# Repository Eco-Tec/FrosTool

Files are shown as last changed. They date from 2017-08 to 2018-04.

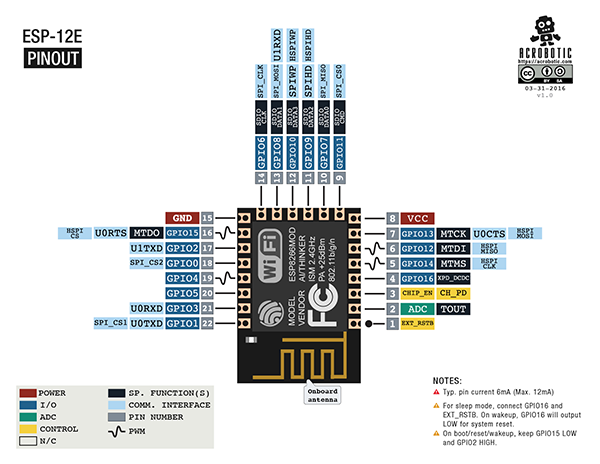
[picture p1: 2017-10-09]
Docs/ESP8266/esp8266_esp12e_pinout.png

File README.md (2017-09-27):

## FrosTool
Herramienta de monitoreo de variables climaticas para la generación de alertas tempranas para mitiga los efectos de las heladas en los cultivos del departamento de Boyaca- Col

# Arbol de directorios
- 3D-Model: Diseños de lo relacionado con las sondas, cajas, soportes, etc.
- Articulo: Contiene un Articulo cort ode investigación enformato IEEE.
- Docs: Contiene la documentación o linkeos hacia la misma (Texto, links, Imagenes)
- Hardware: Referente al hardware desarrollado (Esquemas, PCBs)
- Images: Aqui colocar imagenes solamente referente a el desarrollo del proyecto.
- Software: Principalmente el codigo desarrollado para el proeycto.

# Attributions
Basada en la idea de 
Fabián Andrés Salamanca Figueroa, Willmar Arbey Suarez Rodriguez, Christian Camilo Cárdenas Gamboa
https://github.com/fandres/Monitor-heladas

Este Proyecto
- @fandres
- @maurinc2010

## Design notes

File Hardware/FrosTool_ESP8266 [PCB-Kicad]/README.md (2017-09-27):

# Model 3D on FreeCad
============

License 
======

[Creative Commons Attribution-ShareAlike 4.0 International License](http://creativecommons.org/licenses/by-sa/4.0/)

Attributions
============
See commit details to find the authors of each Part.
- @fandres
- @maurinc2010

Schematic symbols and PCB footprints for ESP8266 modules 
- Copyright 2015,2016 J.Dunmire, kicad-ESP8266 is licensed under the Creative Commons Attribution-ShareAlike
4.0 International License. To view a copy of this license visit
http://creativecommons.org/licenses/by-sa/4.0/.

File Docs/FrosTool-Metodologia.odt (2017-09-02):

Compotentes y dispositivos

Actividad | Tarea | Producto
Sensores
Broker
Materiales sonda | Acondicimiento de la estructura fisica.

Protocolos de telecomunicación

Actividad | Tarea | Producto

Software & Firmware

Actividad | Tarea | Producto
Definir sofware
Definir firmware

App Celular

Actividad | Tarea | Producto
MqttDash

Autonomia Energetica

Actividad | Tarea | Producto
Calcular potencia requerida Modulo
Calcular potencia requerida Broker
Definir autonomia
Calculo Panel
Test baterias
Diseño PCB (Fuente)
Test Panel y fuente

GUI-Touch

Actividad | Tarea | Producto
Definir pantallas
| Perifericos de entrada

Base sensores (Estructura)

Actividad | Tarea | Producto
Diseño de sonda (Fisico)

Algoritmo predicción

Actividad | Tarea | Producto

Nube

Actividad | Tarea | Producto
Dpediente

Automatización

Actividad | Tarea | Producto
Definir tecnologia a usar.

Otras

Actividad | Tarea | Producto
Estado del arte: | Nuemro de sensores por metro cuadrado
Compra anemometro
Protección contra descargas electricas.

https://github.com/Eco-Tec/FrosTool/projects/1

© Esta obra está licenciada bajo la Licencia Creative Commons Atribución 4.0 Internacional. Para ver una copia de esta licencia, visita http://creativecommons.org/licenses/by/4.0/.

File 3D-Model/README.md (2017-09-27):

# Model 3D on FreeCad

# License 

[Creative Commons Attribution-ShareAlike 4.0 International License](http://creativecommons.org/licenses/by-sa/4.0/)

# Attributions

See commit details to find the authors of each Part.
- @fandres

Las piezas o partes usadas y modeladas en 3D de la carpeta parts son diseñadas por terceros

├── Broker
│   └── orange-pi-zero-v1-1-1-carly_mx.2
└── Node
    ├── 18650-by_Nursultan_Uzbekov
    ├── DHT22-by_Gistroy
    ├── esp8266-by_Andrey_Chirva
    ├── esp8266-esp01-by_ceodor_schumacher
    └── nodemcu-lua-wifi-by_Francisco_Castells

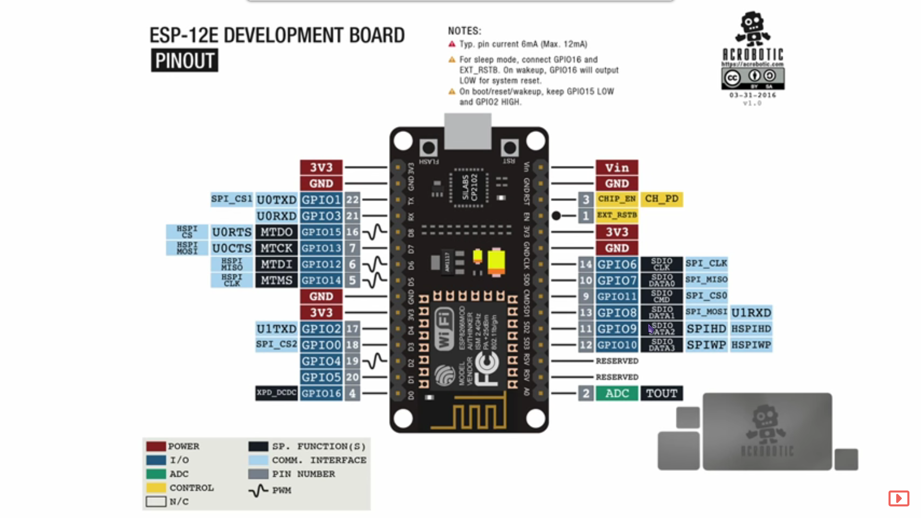
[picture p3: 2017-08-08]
Docs/ESP8266/ESP-12E-Placa de desarrollo.png

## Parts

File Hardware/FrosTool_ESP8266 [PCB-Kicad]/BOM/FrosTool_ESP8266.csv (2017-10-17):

Title | PCB-Kicad FrosTool
Revision | 1
Date
Generated | lun 16 oct 2017 20:20:48 -05
Company | Eco-Tec
Comment 1 | @maurinc2010
Comment 2 | @fAndReS
Comment 3
Comment 4
Total Parts | 38
Total Unique Parts | 28
Ref | Qty | Value | Footprint
C1 | 1 | 100nF | Capacitors_SMD:C_0805
C2 C3 | 2 | 10uF | Capacitors_SMD:c_elec_4x5.3
C4 | 1 | 10uF | Capacitors_SMD:C_0805
D1 | 1 | LED_DEBUG | LEDs:LED-3MM
D2 | 1 | CHRG_R | LEDs:LED-3MM
D3 | 1 | STDBY_G | LEDs:LED-3MM
J5 | 1 | DATA_S1 | Pin_Headers:Pin_Header_Straight_1x01
J8 | 1 | GPIO14(D/A) | Pin_Headers:Pin_Header_Straight_1x01
J1 | 1 | IN_PANEL | Pin_Headers:Pin_Header_Straight_1x02_Pitch2.00mm
J2 | 1 | BATERIA | Pin_Headers:Pin_Header_Straight_1x02_Pitch2.00mm
J14 J15 J13 | 3 | GND | Pin_Headers:Pin_Header_Straight_1x01
J10 J11 J12 | 3 | V3.3 | Pin_Headers:Pin_Header_Straight_1x01
J3 | 1 | TX_RX | Pin_Headers:Pin_Header_Straight_1x02_Pitch2.00mm
J6 | 1 | GPIO12(D/A) | Pin_Headers:Pin_Header_Straight_1x01
J7 J4 J9 | 3 | GPIO13(D) | Pin_Headers:Pin_Header_Straight_1x01
J16 | 1 | BAT+
Q1 | 1 | 2N3904 | TO_SOT_Packages_SMD:SOT-23
R5 | 1 | 470 | Resistors_SMD:R_1206
R4 R7 R8 | 3 | 1k | Resistors_SMD:R_1206
R3 R1 | 2 | 4.7k | Resistors_SMD:R_1206
R2 | 1 | 0 | Resistors_SMD:R_1206
R6 | 1 | 0.4 | Resistors_SMD:R_1206
R9 | 1 | 1.2k | Resistors_SMD:R_1206
SW2 | 1 | Flash | Buttons_Switches_SMD:SW_SPST_B3U-1000P
SW1 | 1 | Reset | Buttons_Switches_SMD:SW_SPST_B3U-1000P
U2 | 1 | ESP-12E | ESP8266:ESP-12E_SMD
U1 | 1 | HT7333-1 | TO_SOT_Packages_SMD:SOT89-3_Housing
U3 | 1 | TP4056 | Housings_SOIC:SOIC-8_3.9x4.9mm_Pitch1.27mm
BOM made with KICAD_BOM_WIZARD (https://github.com/HashDefineElectronics/KiCad_BOM_Wizard.git)
Generated lun 16 oct 2017 20:20:48 -05

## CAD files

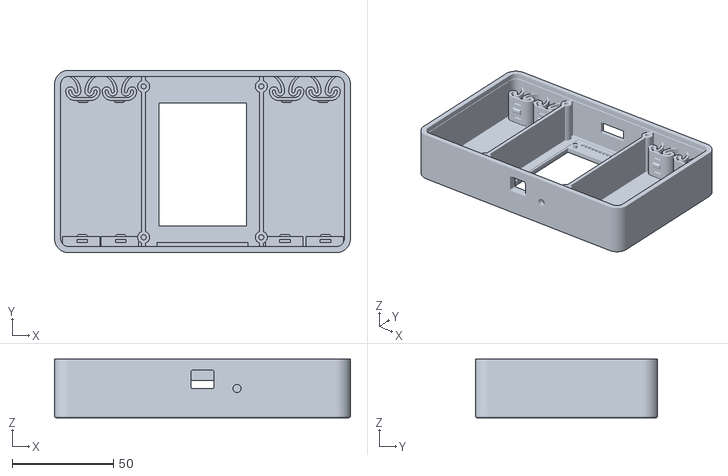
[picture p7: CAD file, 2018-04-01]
3D-Model/Broker/Case_Broker-A.stl
146.0 x 90.0 x 29.0

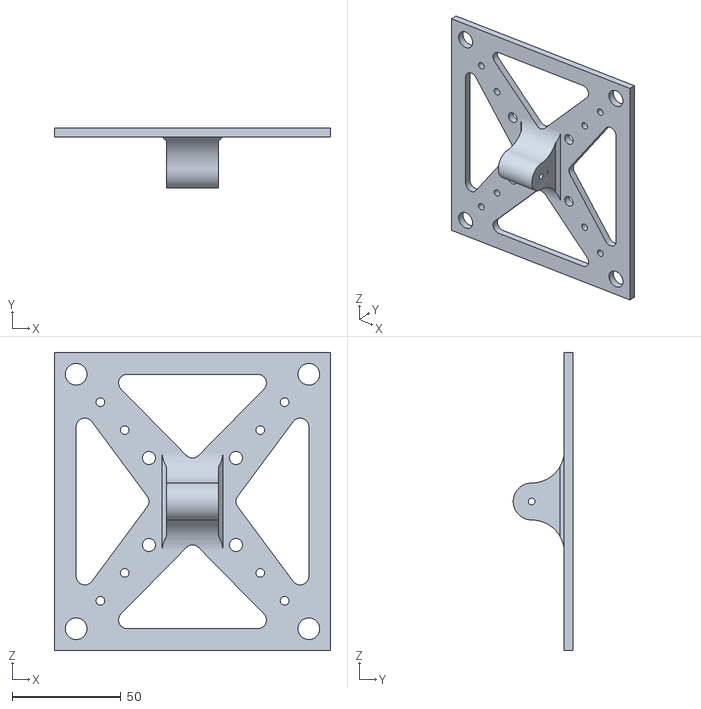
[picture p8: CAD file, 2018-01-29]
3D-Model/Node/SUPP_3.stl
127.0 x 27.4 x 137.0

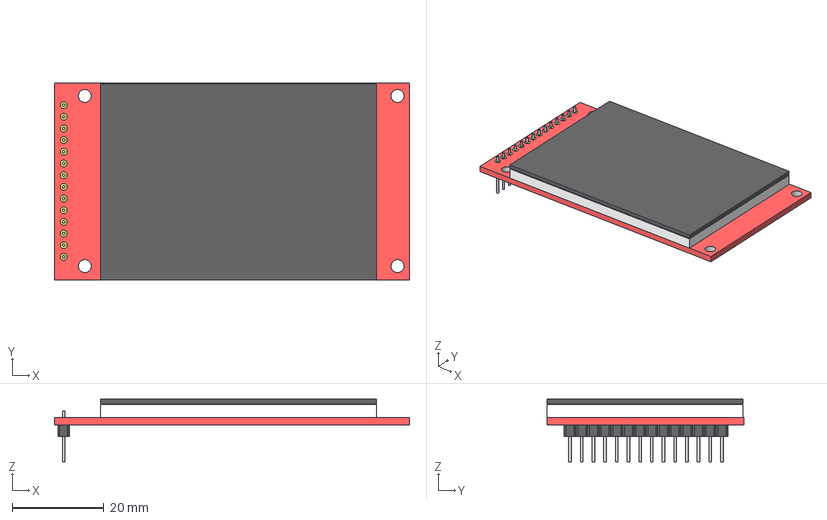
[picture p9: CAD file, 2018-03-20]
3D-Model/Parts/Broker/ili9341-ts-Christophe Chaloin/ILI9341-2_4.step
77.2 x 42.8 x 13.6 mm
LCD
Socket
Pads
Touchscreen
Pin_Header_1x14
PCB

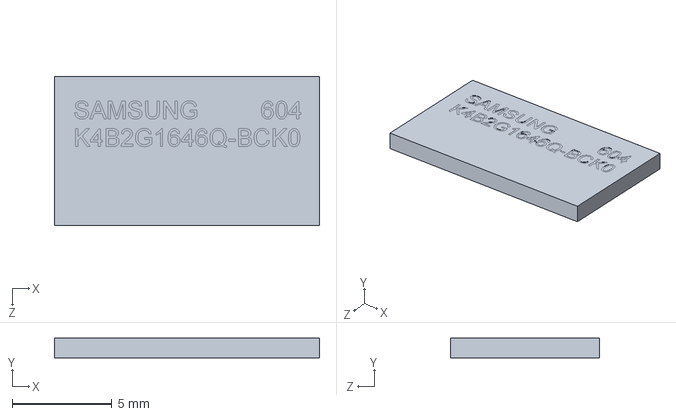
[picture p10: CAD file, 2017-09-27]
3D-Model/Parts/Broker/orange-pi-zero-v1-1-1-carly_mx.2/Orange Pi Zero v1_1/parts/SAMSUNG mem.SLDPRT
13.3 x 1.00 x 7.50 mm

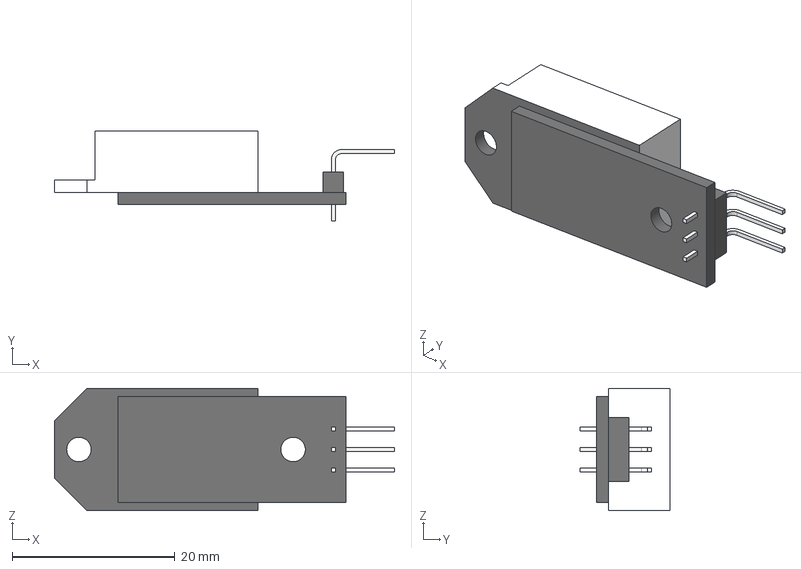
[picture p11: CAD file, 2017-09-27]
3D-Model/Parts/Node/DHT22-by_Gistroy/DHT22-by_Gistroy.STEP
41.8 x 11.0 x 15.0 mm

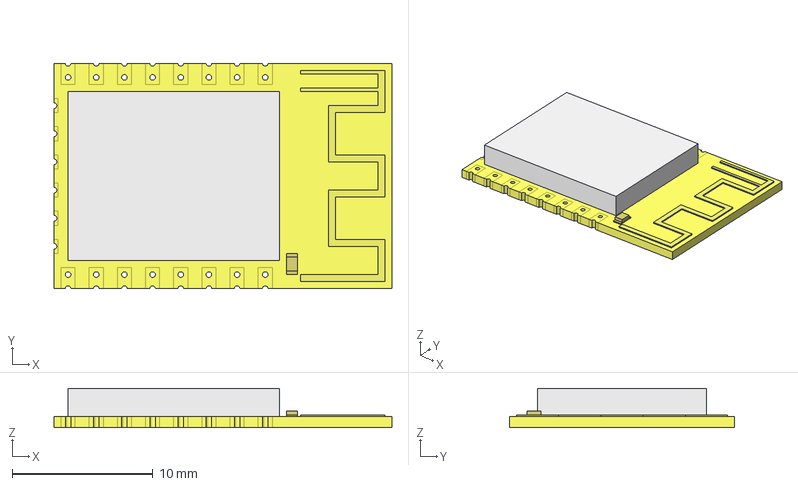
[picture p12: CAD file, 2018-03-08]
3D-Model/Parts/Node/esp8266-by_Christophe Chaloin/ESP8266-12.FCStd
24.0 x 16.0 x 2.80 mm
Cap
PCB
LED

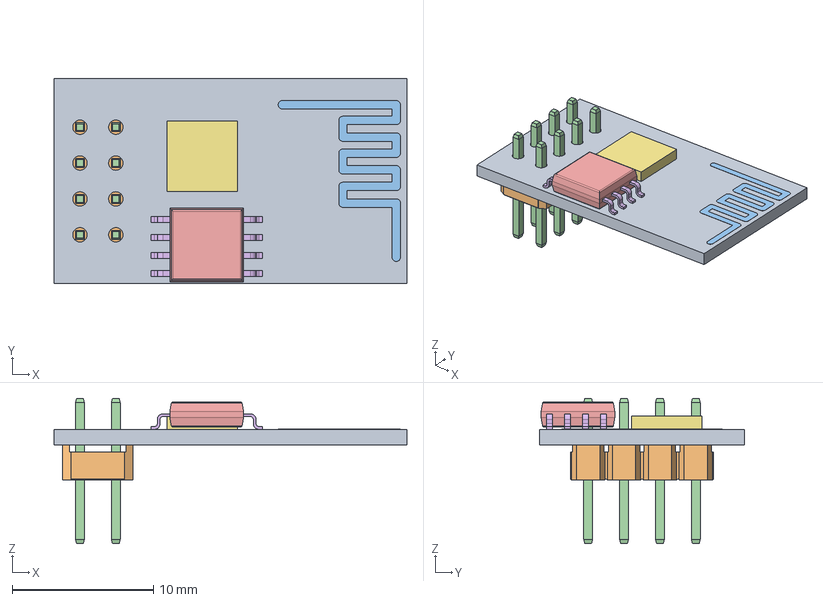
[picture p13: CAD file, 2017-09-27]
3D-Model/Parts/Node/esp8266-esp01-by_ceodor_schumacher/esp8266-esp01-by_ceodor_schumacher.stp
25.0 x 14.5 x 10.3 mm

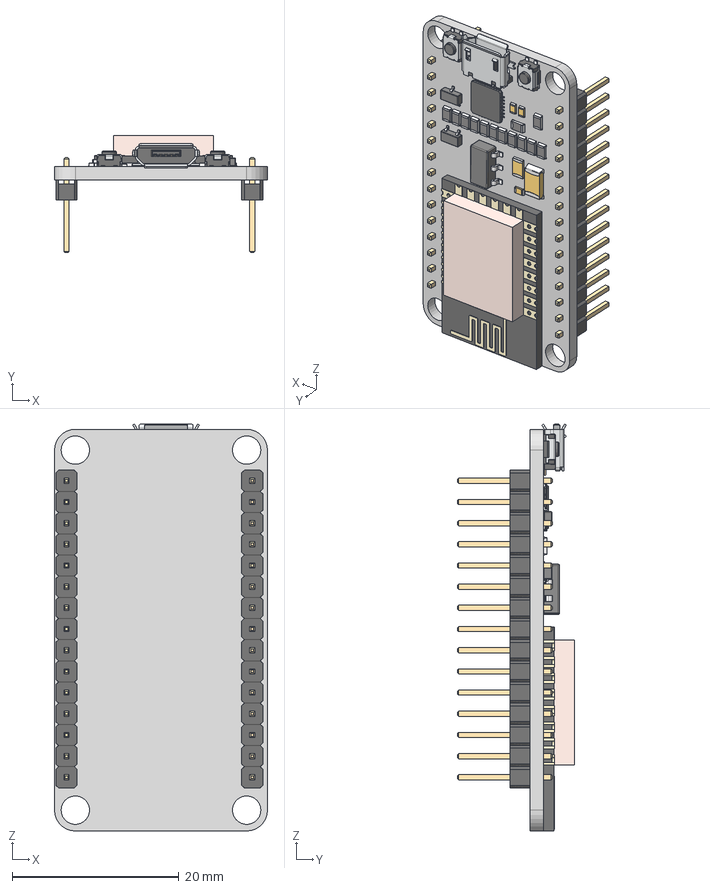
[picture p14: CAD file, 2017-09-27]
3D-Model/Parts/Node/nodemcu-lua-wifi-by_Francisco_Castells/nodemcu-lua-wifi-by_Francisco_Castells.stp
25.6 x 14.1 x 48.8 mm
micro usb shell
micro usb internal
micro usb contact x 5
switch v1
switch v1 (1)
spacer x 15
pin x 15
spacer (1) (1) x 15
pin (1) (1) x 15
TSOP-5 v4 v1
TSOP-5 v4 v1 (1)
TSOP-5 v4 v1 (1) (1)
R0805-NO v1 x 13
R0805-NO v1 (1) x 2
R0805-NO v1 (1) (1)
R0805-NO v1 (1) (2)
R0805-NO v1 (1) (3)
Cuerpo Microprocesador v1

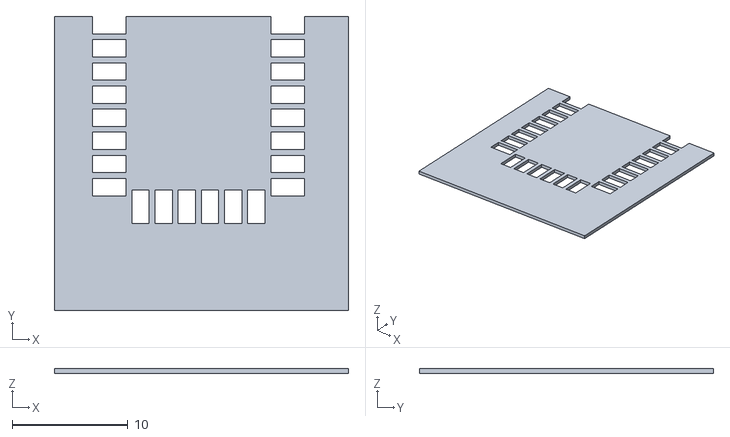
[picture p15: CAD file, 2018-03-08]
Hardware/FrosTool_ESP8266 [PCB-Kicad]/PCB/Stencil/F.Mask.stl
25.4 x 25.4 x 0.4

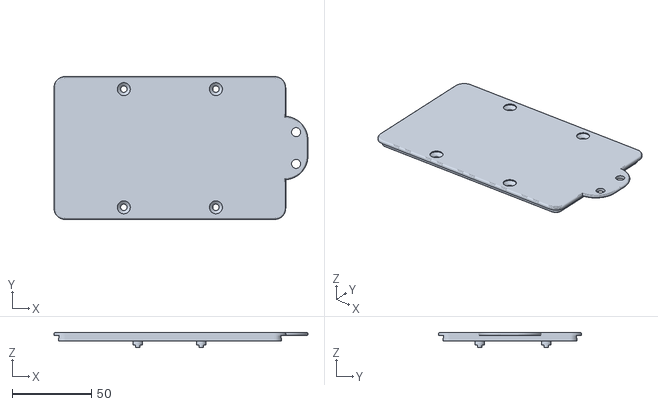
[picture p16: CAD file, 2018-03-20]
3D-Model/Broker/Case_Broker-B.stl
160.0 x 90.0 x 9.60

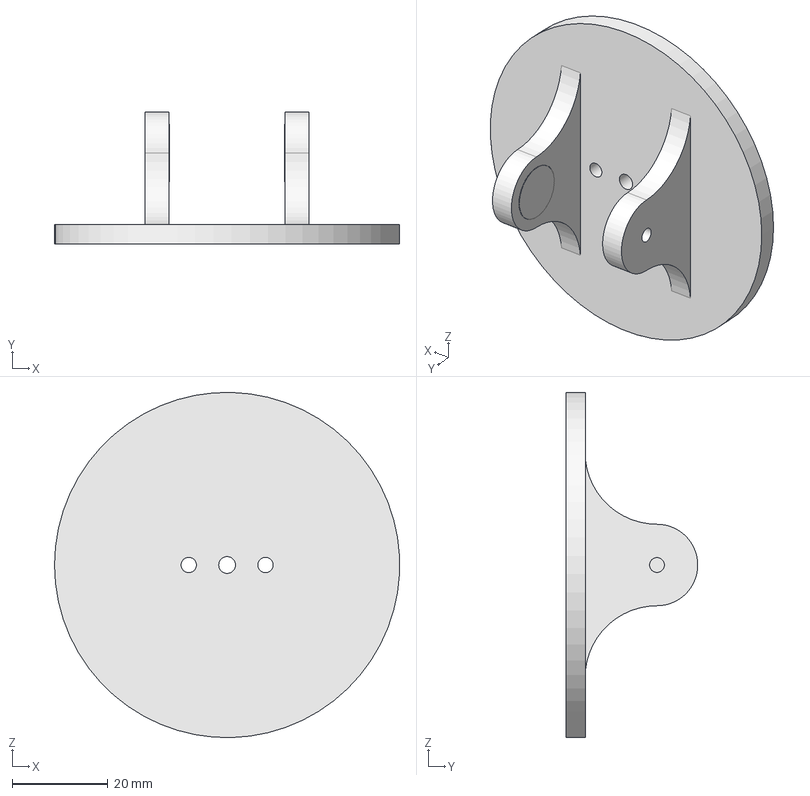
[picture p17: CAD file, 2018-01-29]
3D-Model/Node/SUPP_2.step
71.9 x 27.4 x 72.0 mm

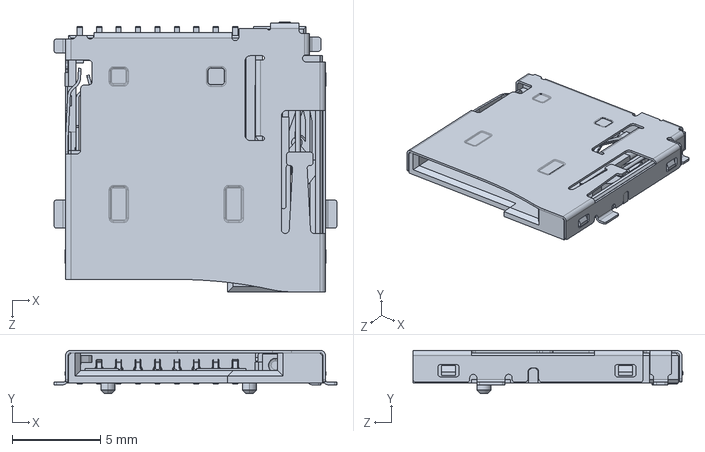
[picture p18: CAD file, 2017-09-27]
3D-Model/Parts/Broker/orange-pi-zero-v1-1-1-carly_mx.2/Orange Pi Zero v1_1/parts/MEM2055-00-190-01-A_revG.SLDPRT
16.0 x 2.45 x 15.2 mm

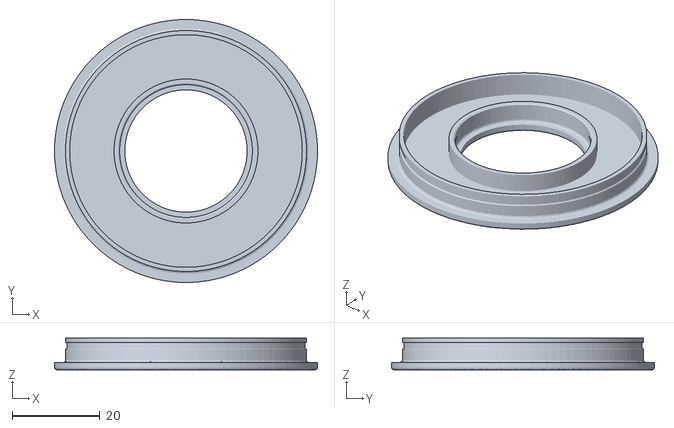
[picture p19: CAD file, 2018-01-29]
3D-Model/Node/case_S_2.stl
59.8 x 59.8 x 7.16

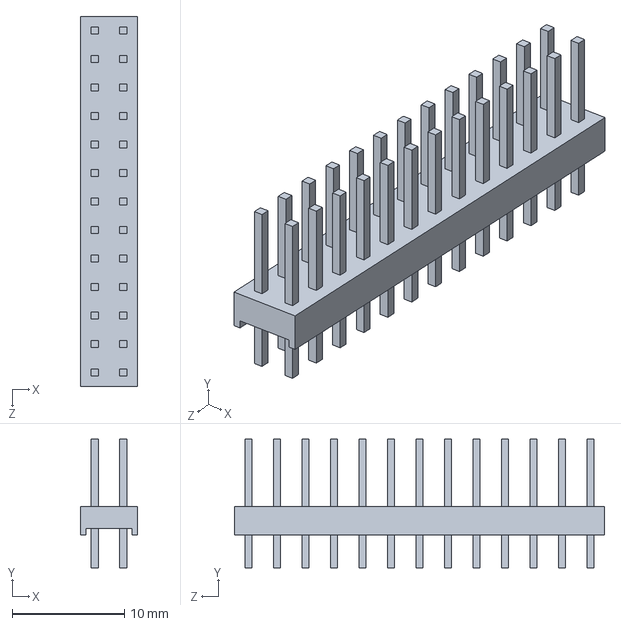
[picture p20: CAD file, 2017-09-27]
3D-Model/Parts/Broker/orange-pi-zero-v1-1-1-carly_mx.2/Orange Pi Zero v1_1/parts/PLD-26.SLDPRT
5.08 x 11.5 x 33.0 mm

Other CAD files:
3D-Model/Node/Case_FrossTool.fcstd
3D-Model/Parts/Broker/orange-pi-zero-v1-1-1-carly_mx.2/Orange Pi Zero v1_1/parts/PLS-01.SLDPRT
3D-Model/Node/FrosTool_ESP8266.FCStd
3D-Model/Node/Node.fcstd
3D-Model/Node/Node_1.stl
3D-Model/Node/SUPP_2.stl
3D-Model/Node/support_bat.step
3D-Model/Node/support_bat.stl
3D-Model/Parts/Broker/ili9341-ts-Christophe Chaloin/ILI9341-2_4.FCStd
3D-Model/Parts/Broker/orange-pi-zero-v1-1-1-carly_mx.2/Orange Pi Zero v1_1/parts/Allwinner-H2.SLDPRT
3D-Model/Parts/Broker/orange-pi-zero-v1-1-1-carly_mx.2/Orange Pi Zero v1_1/parts/Boderboard - Orange Pi zero v1.1.SLDPRT
3D-Model/Parts/Broker/orange-pi-zero-v1-1-1-carly_mx.2/Orange Pi Zero v1_1/parts/MicroUSB-B_Molex_105017-0001.SLDPRT
3D-Model/Parts/Broker/orange-pi-zero-v1-1-1-carly_mx.2/Orange Pi Zero v1_1/parts/PLD-13.SLDPRT
3D-Model/Parts/Broker/orange-pi-zero-v1-1-1-carly_mx.2/Orange Pi Zero v1_1/parts/USB.SLDPRT
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

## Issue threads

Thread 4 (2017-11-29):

Capas Seguridad

fandres, 2017-11-29:
Capas de hardware y software que permitan adecuar el dispositivo a situaciones que pongan el risco la privacidad y la seguridad de los datos y del usuario.

fandres, 2017-12-22:
Cambio puertos
Cifrar conexión
Cifrar Info
Permisos
Contraseñas

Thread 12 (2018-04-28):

PCB Broker V2.0 :Esquematico Espruino

fandres, 2018-04-28:

fandres, 2018-04-28:
- Buscar esquemático Espruino Pico

fandres, 2018-04-28:
https://github.com/espruino/EspruinoBoard/tree/master/Pico

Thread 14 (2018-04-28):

PCB

fandres, 2018-04-28:

fandres, 2018-04-28:
Error usando transistor
Faltaban 2 resistencias.

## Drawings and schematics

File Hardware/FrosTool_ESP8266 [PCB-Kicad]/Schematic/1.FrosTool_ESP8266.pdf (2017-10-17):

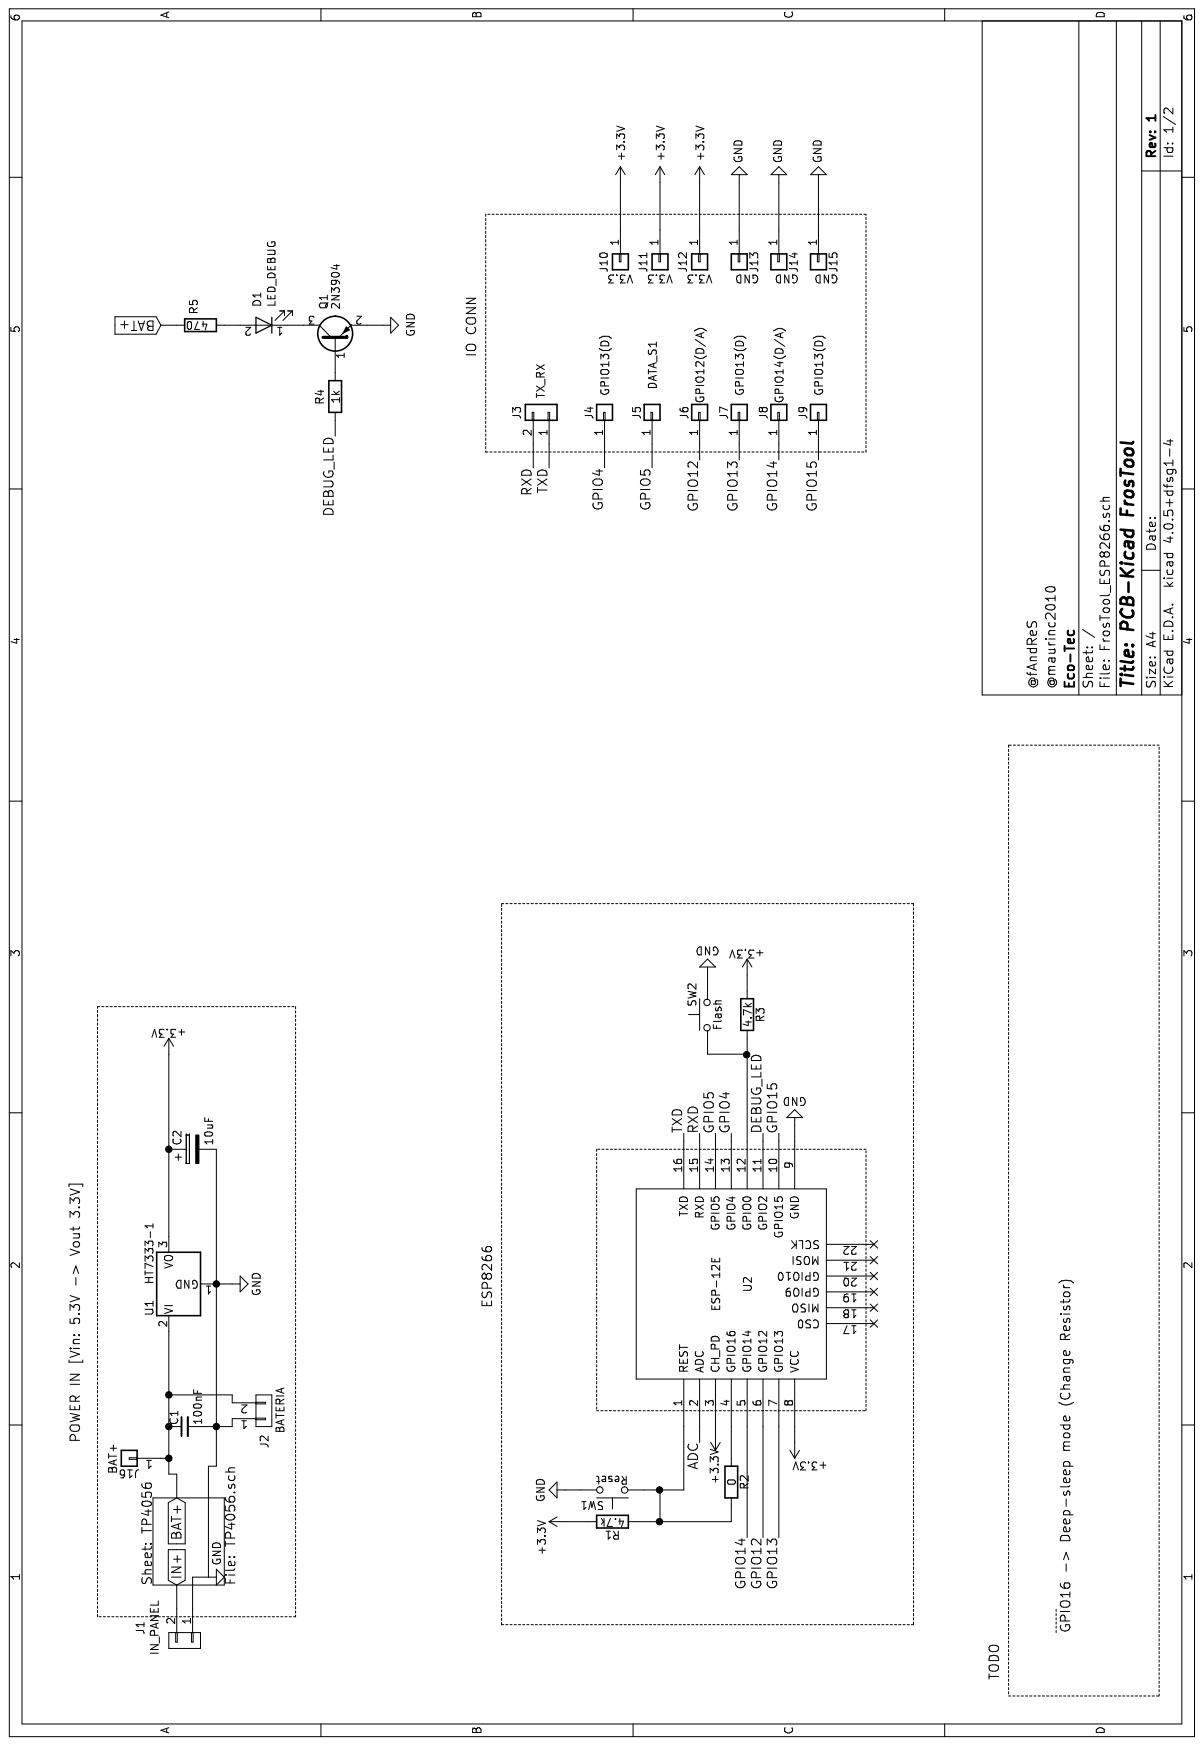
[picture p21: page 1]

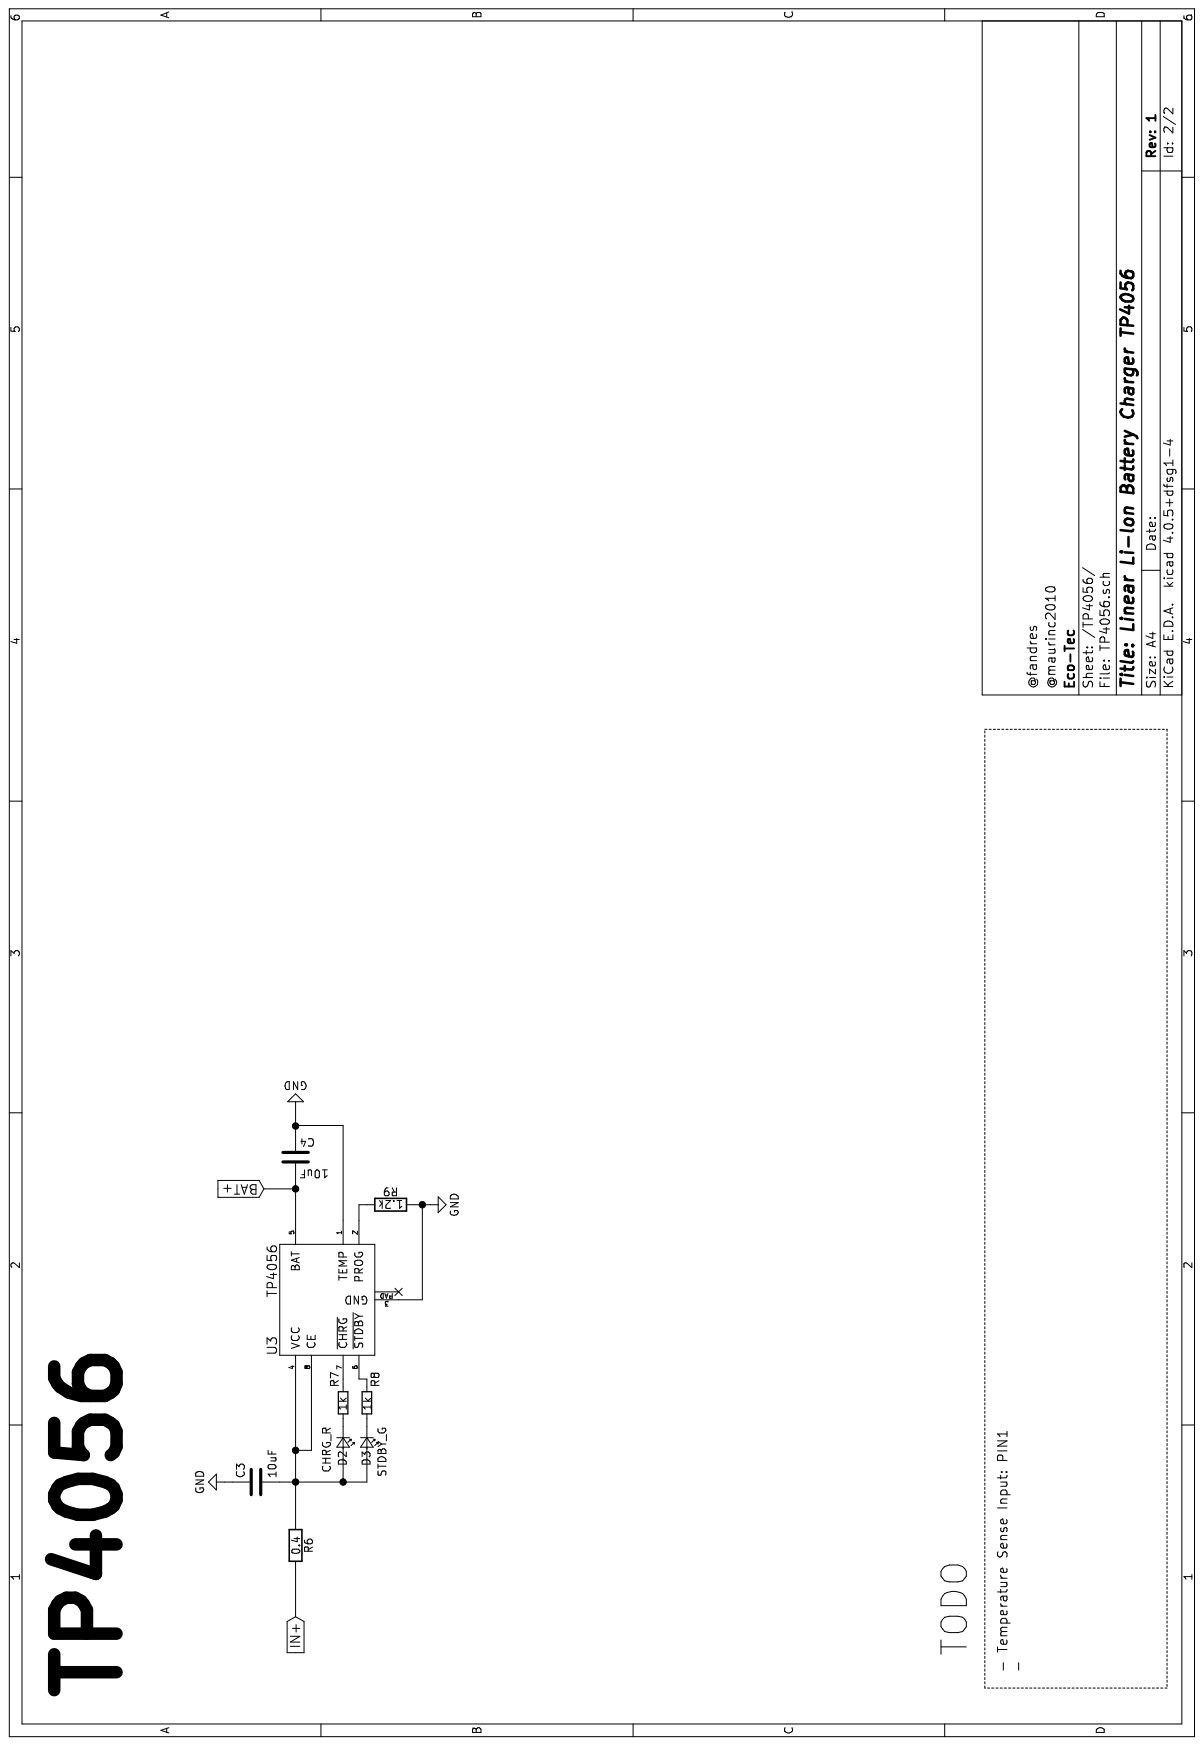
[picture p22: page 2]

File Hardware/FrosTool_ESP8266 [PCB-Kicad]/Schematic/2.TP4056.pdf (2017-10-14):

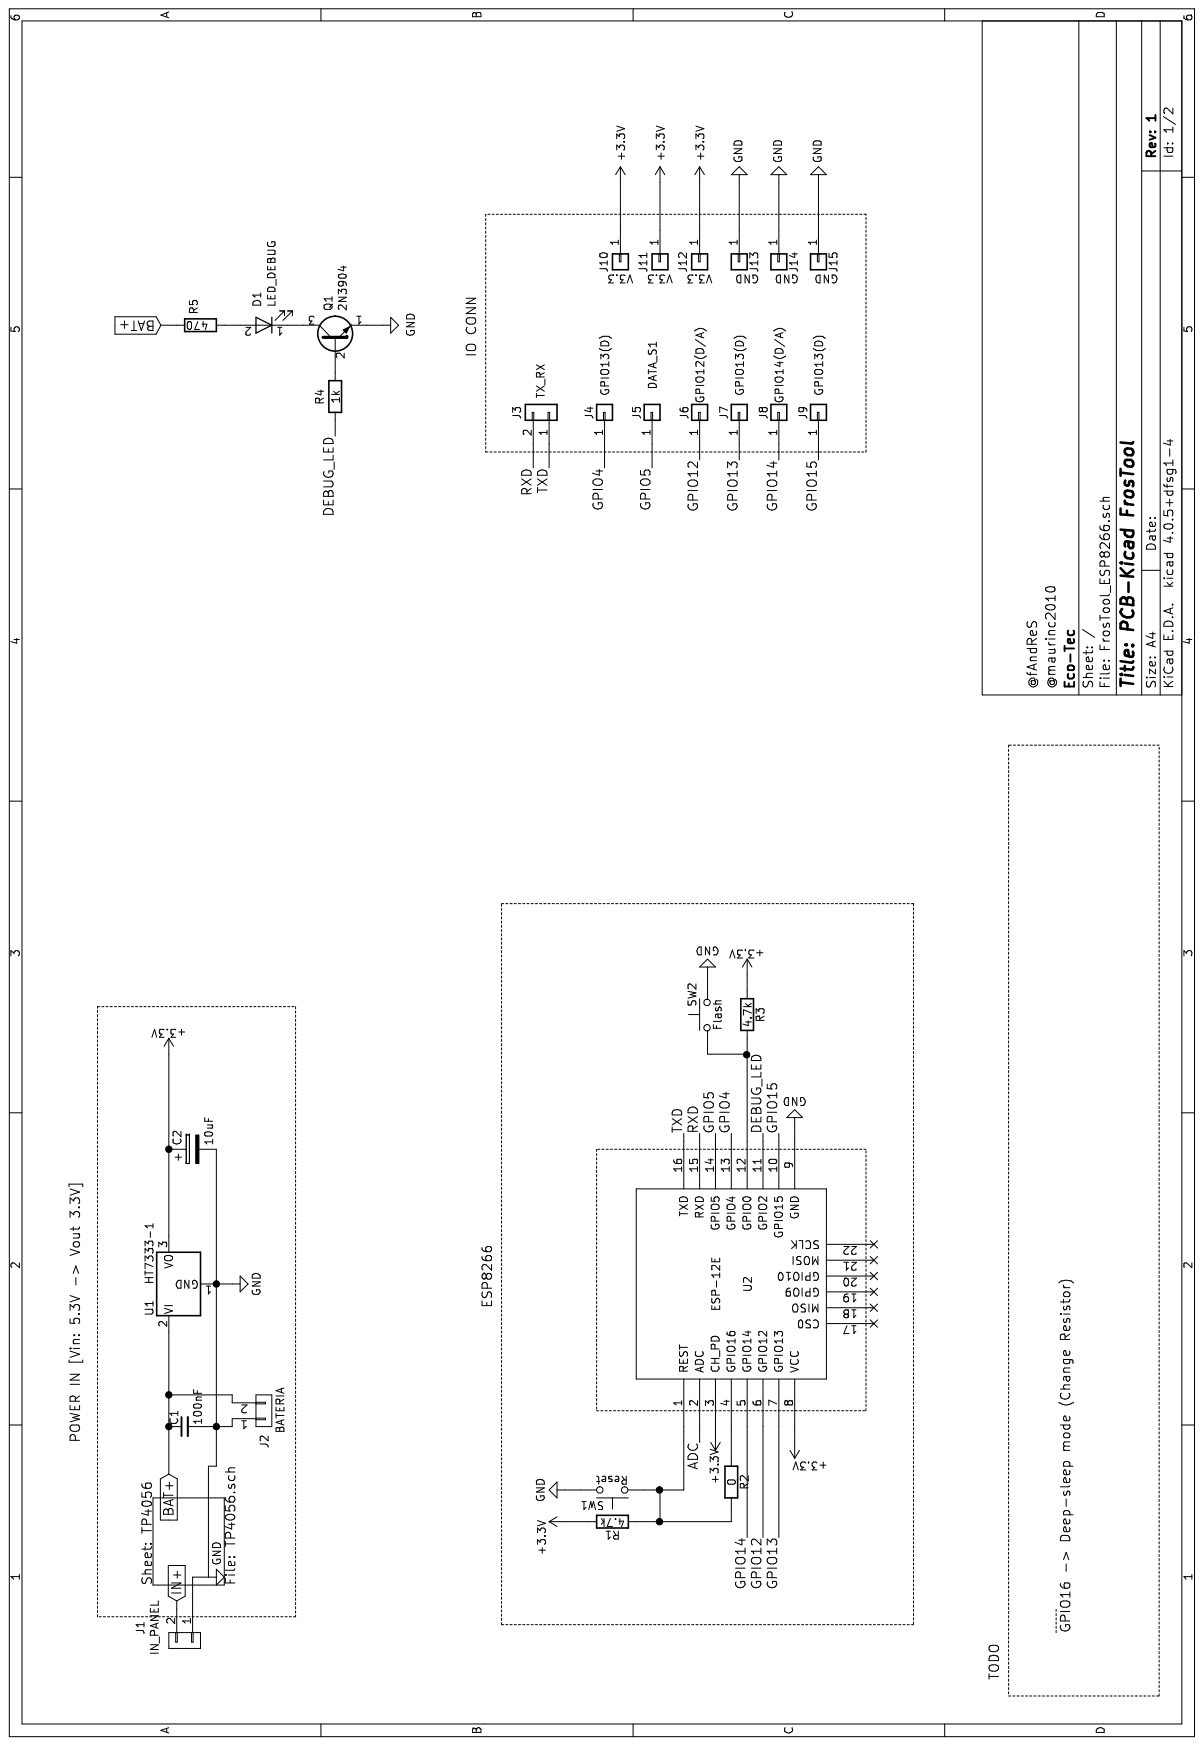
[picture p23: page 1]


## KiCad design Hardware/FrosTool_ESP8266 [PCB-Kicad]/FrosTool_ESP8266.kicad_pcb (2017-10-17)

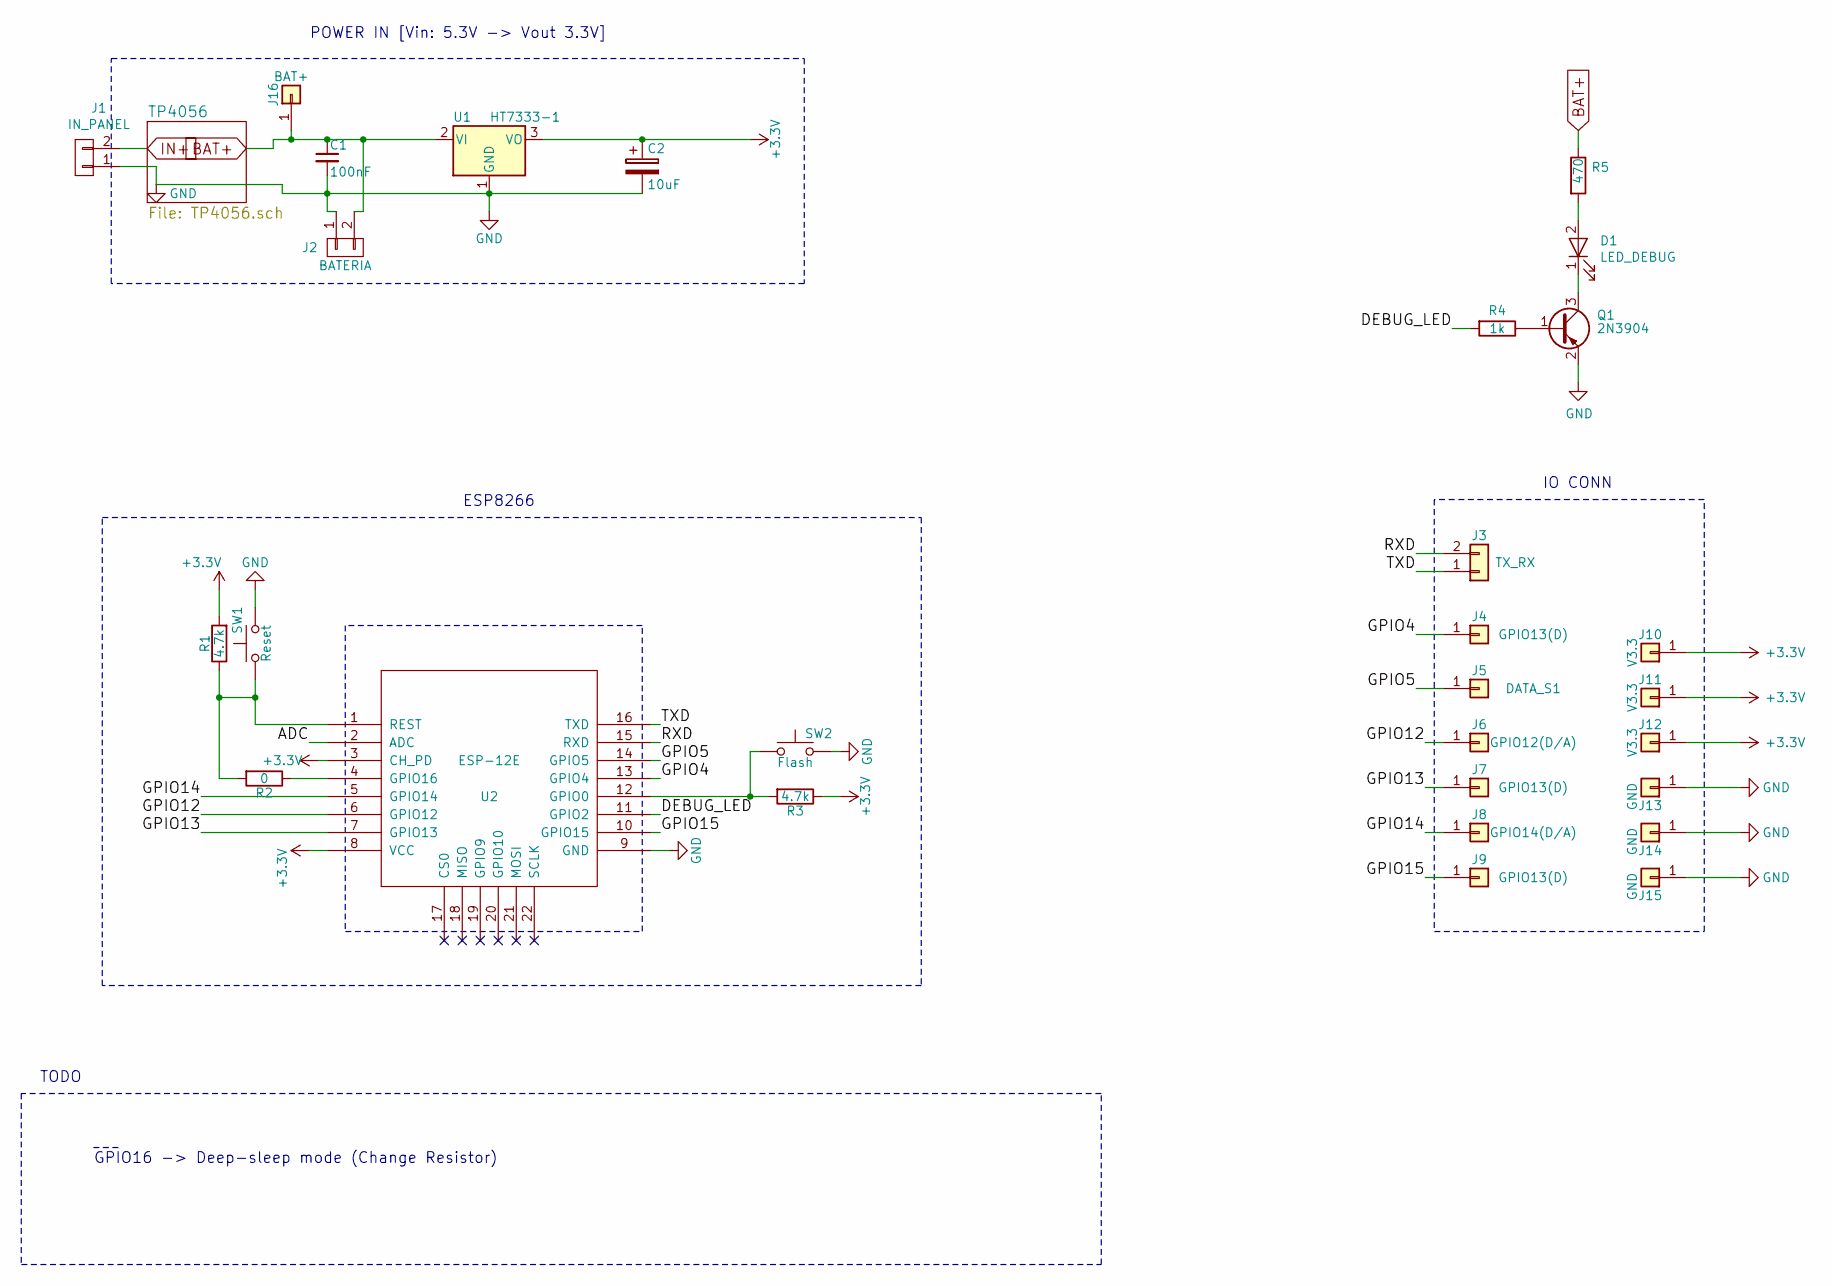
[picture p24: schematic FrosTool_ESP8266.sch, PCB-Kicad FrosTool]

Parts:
C1: 100nF; C_0805
C2: 10uF; c_elec_4x5.3
D1: LED_DEBUG; LED-3MM
J1: IN_PANEL; Pin_Header_Straight_1x02_Pitch2.00mm
J2: BATERIA; Pin_Header_Straight_1x02_Pitch2.00mm
J3: TX_RX; Pin_Header_Straight_1x02_Pitch2.00mm
J4, J7, J9: GPIO13(D); Pin_Header_Straight_1x01
J5: DATA_S1; Pin_Header_Straight_1x01
J6: GPIO12(D/A); Pin_Header_Straight_1x01
J8: GPIO14(D/A); Pin_Header_Straight_1x01
J10, J11, J12: V3.3; Pin_Header_Straight_1x01
J13, J14, J15: GND; Pin_Header_Straight_1x01
J16: BAT+; Pin_Header_Straight_1x01
Q1: 2N3904; SOT-23
R1, R3: 4.7k; R_1206
R2: 0; R_1206
R4: 1k; R_1206
R5: 470; R_1206
SW1: Reset; SW_SPST_B3U-1000P
SW2: Flash; SW_SPST_B3U-1000P
U1: HT7333-1; SOT89-3_Housing
U2: ESP-12E; ESP-12E_SMD

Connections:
+3V3: C2.1, J10.1, J11.1, J12.1, R1.2, R3.1, U1.3 (VO), U2.3 (CH_PD), U2.8 (VCC)
/ADC: U2.2 (ADC)
/DEBUG_LED: R4.2, U2.11 (GPIO2)
/GPIO4: J4.1, U2.13 (GPIO4)
/GPIO5: J5.1, U2.14 (GPIO5)
/GPIO12: J6.1, U2.6 (GPIO12)
/GPIO13: J7.1, U2.7 (GPIO13)
/GPIO14: J8.1, U2.5 (GPIO14)
/GPIO15: J9.1, U2.10 (GPIO15)
/RXD: J3.2, U2.15 (RXD)
/TXD: J3.1, U2.16 (TXD)
BAT+: C1.1, J2.2, J16.1, R5.1, U1.2 (VI); also elsewhere on the board
GND: C1.2, C2.2, J1.1, J2.1, J13.1, J14.1, J15.1, Q1.2 (E), SW1.2, SW2.2, U1.1 (GND), U2.9 (GND); also elsewhere on the board
IN+: J1.2; also elsewhere on the board
unnamed: D1.1 (K), Q1.3 (C)
unnamed: D1.2 (A), R5.2
unnamed: Q1.1 (B), R4.1
unnamed: R1.1, R2.2, SW1.1, U2.1 (REST)
unnamed: R2.1, U2.4 (GPIO16)
unnamed: R3.2, SW2.1, U2.12 (GPIO0)

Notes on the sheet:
POWER IN [Vin: 5.3V -> Vout 3.3V]
TODO
GPIO16 -> Deep-sleep mode (Change Resistor)
ESP8266
IO CONN

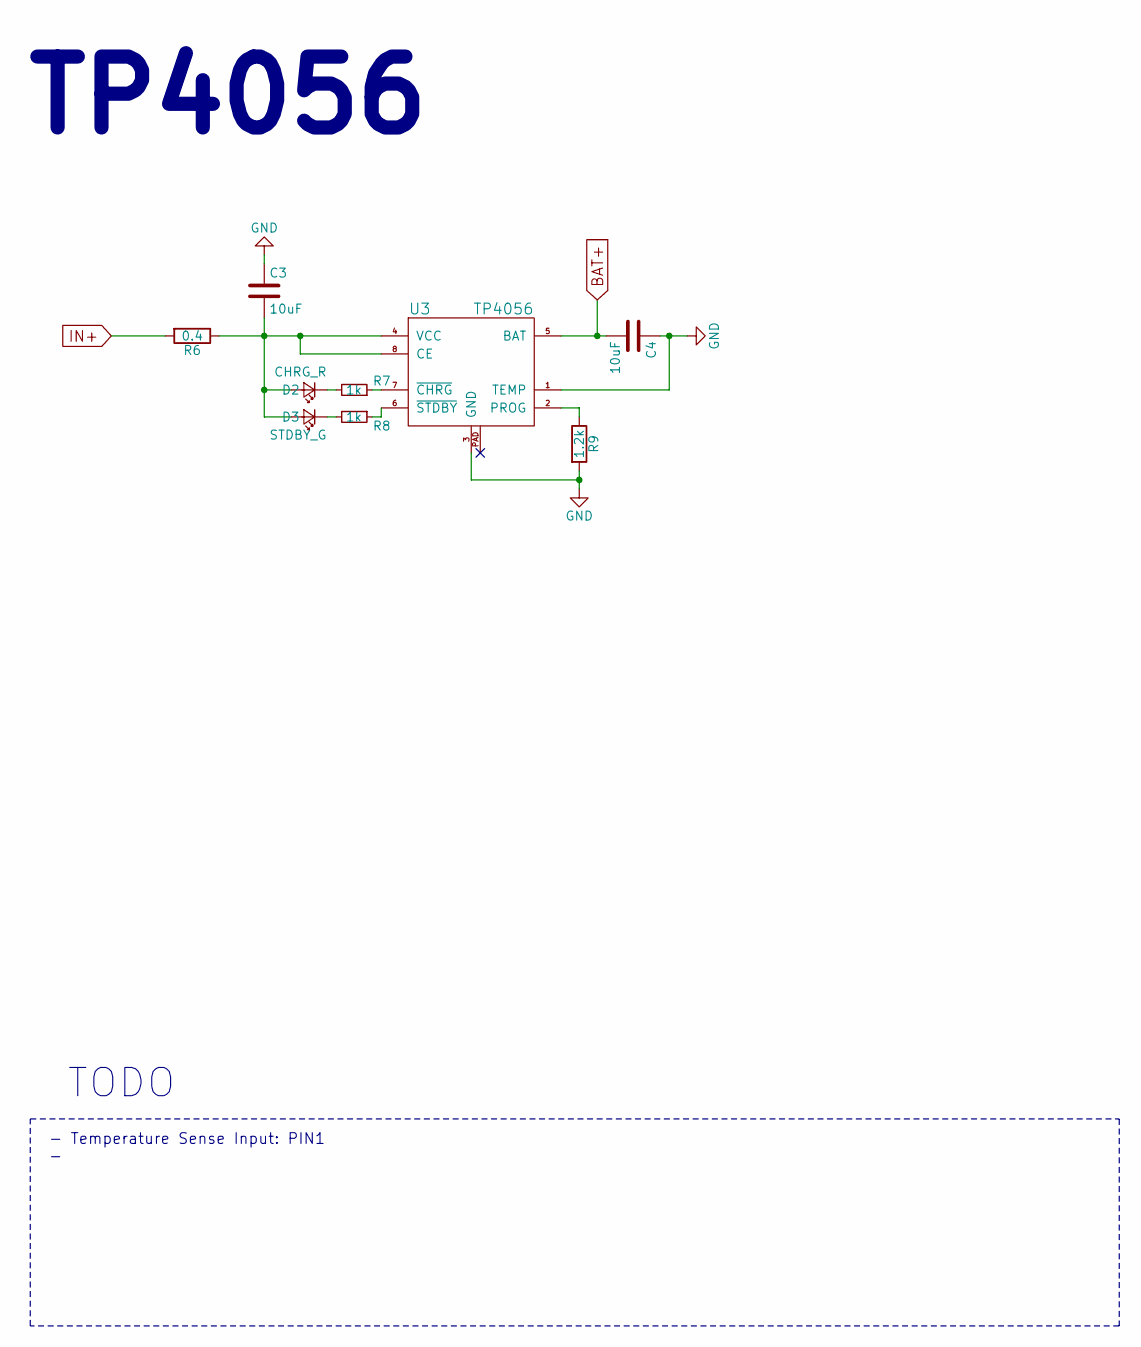
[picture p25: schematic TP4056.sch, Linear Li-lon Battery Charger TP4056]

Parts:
C3: 10uF; c_elec_4x5.3
C4: 10uF; C_0805
D2: CHRG_R; LED-3MM
D3: STDBY_G; LED-3MM
R6: 0.4; R_1206
R7, R8: 1k; R_1206
R9: 1.2k; R_1206
U3: TP4056; SOIC-8_3.9x4.9mm_Pitch1.27mm

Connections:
BAT+: C4.2, U3.5 (BAT); also elsewhere on the board
GND: C3.1, C4.1, R9.2, U3.1 (TEMP), U3.3 (GND); also elsewhere on the board
IN+: R6.2; also elsewhere on the board
unnamed: C3.2, D2.2 (A), D3.2 (A), R6.1, U3.4 (VCC), U3.8 (CE)
unnamed: D2.1 (K), R7.2
unnamed: D3.1 (K), R8.2
unnamed: R7.1, U3.7 (~CHRG)
unnamed: R8.1, U3.6 (~STDBY)
unnamed: R9.1, U3.2 (PROG)

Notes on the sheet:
- Temperature Sense Input: PIN1 -
TODO
TP4056

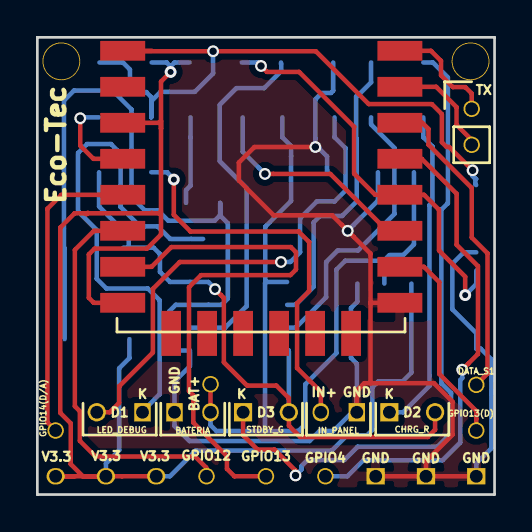
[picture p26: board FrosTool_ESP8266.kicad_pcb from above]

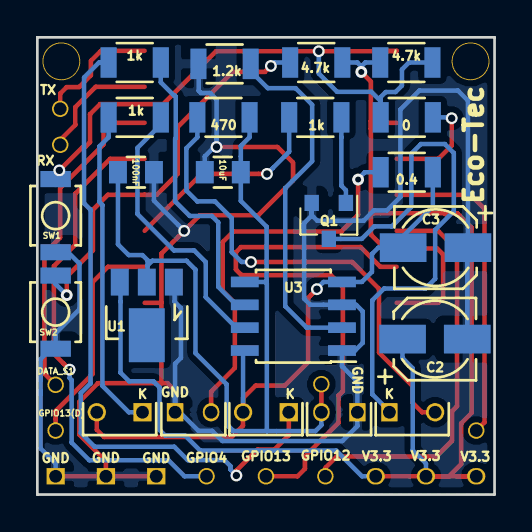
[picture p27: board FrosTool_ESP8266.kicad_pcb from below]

Board: 2 copper layers, 25.4 x 25.4 mm, 40 parts (18 on the bottom side), 25 nets.

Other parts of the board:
Drill2mm_1, Drill222_2: SolderWirePad_single_1-2mmDrill

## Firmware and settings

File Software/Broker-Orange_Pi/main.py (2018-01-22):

#!/usr/bin/env python
# -*- coding: utf-8 -*-
"""
    DESCRIPCI?N...
    This software is free, licensed y distributed under GPL v3.
    (see COPYING) WITHOUT ANY WARRANTY.
    You can see a description of license here: http://www.gnu.org/copyleft/gpl.html
    Copyright(c) 2017 by fandres "Fabian Salamanca" <fabian.salamanca@openmailbox.org>
                         Marlon...
    Distributed under GPLv3+
    Hardware: Orange Pi Zero
    Pin distribution(Default)
    Pin X [BOARD]    ->  Pin: Alarm(Buzer): [OUT]
    Pin X [BOARD]    ->  Pin: Stop Alarm(Buzer): [IN]
    Configure wifi and MQTT
"""


__author__ = "Fabian A. Salamanca F."
__copyright__ = "Copyright 2017, Eco-Tec"
__credits__ = ["Fabian A. Salamanca F, Marlon Mauricio Moreno"]
__license__ = "GPL V3.0"
__version__ = "1.4.1"
__maintainer__ = __author__
__email__ = "fabian.salamanca@gmail.com"

# imports hardware
#import OPi.GPIO as GPIO
# imports modulos
from config import BROKER_IP, USER, PASSWORD
#from config import BROKER
import paho.mqtt.client as mqtt
# imports library python
from time import sleep
import threading
from time import time, sleep
import time
import re
import queue
from config import*  # IMPORTAR SOLO LO USADO

##########----------    Class   ----------##########


class Archivos ():
    def __init__(self):
        self.plantilla = ""  # open("plantilla.txt",'r')
        self.file = ""

    def crear_file(self, name_file, broker, ubicacion, nodo, sensor, var):
        self.plantilla = open("plantilla.txt", 'r')
        self.file = open(name_file, 'w')
        self.encabezado(broker, ubicacion, sensor, nodo, var)
        self.file.close()
        self.plantilla.close()

    def encabezado(self, broker, ubicacion, sensor, nodo, var):
        linea = self.plantilla.readline()
        while linea != "":

            if linea == "# Copyrigh\n":
                #m=re.sub("\s", __copyright__ ,linea)
                self.file.write("# " + __copyright__ + "\n")
            elif linea == "# License\n":
                # print("# "+__copyright__+"\n")
                m = re.sub("\n", "  ," + __license__ + "\n", linea)
                # print(m)
                self.file.write(m)
            elif linea == "# Version\n":
                # print("# "+__copyright__+"\n")
                m = re.sub("\n", "  ," + __version__ + "\n", linea)
                # print(m)
                self.file.write(m)
            elif linea == "# Generado por el Broker\n":
                m = re.sub("\n", "  ," + broker + "\n", linea)
                # print(m)
                self.file.write(m)
            elif linea == "# fecha\n":
                m = re.sub("\n", "  ," +
                           time.strftime("%d/%m/%y") + "\n", linea)
                # print(m)
                self.file.write(m)
            elif linea == "# UBICACION\n":
                m = re.sub("\n", "  " + ubicacion + "\n", linea)
                # print(m)
                self.file.write(m)
            elif linea == "# SENSOR\n":
                m = re.sub("\n", "  ," + sensor + "\n", linea)
                # print(m)
                self.file.write(m)
            elif linea == "# NODO\n":
                m = re.sub("\n", "  ," + nodo + "\n", linea)
                # print(m)
                self.file.write(m)
            elif linea == "TIME,var\n":
                m = re.sub("var", var + "\n", linea)
                self.file.write(m)
            else:
                # print(linea)
                self.file.write(linea)
            linea = self.plantilla.readline()

##########----------    Class   ----------##########


class Prediction(object):
    """Algoritmo que permite hasta cierto grado la prediccion"""

    def __init__(self, arg):
        super(Prediction, self).__init__()
        self.arg = arg


##########----------    Class   ----------##########
class ClassName(object):
    """docstring for ."""

    def __init__(self, arg):
        super(self).__init__()
        self.arg = arg
        # Control(object):
    """Manipula los actuadores, como la alarma visual sonora,
    ademas de otros actuadores como los sistemas de riego..."""

    def __init__(self, PIN_Alarm=17, PIN_Sp_A=4):
        super(Actuators, self).__init__()
        self.PIN_ALARMA = PIN_Alarm
        self.PIN_STOP_ALARMA = PIN_Sp_A
        self._alarm_state = 0
        self._SET_TEMP = 0
        self._SET_HUM = 80
        GPIO.output(PIN_ALARMA, False)
        GPIO.setup(PIN_STOP_ALARMA, GPIO.IN, pull_up_down=GPIO.PUD_DOWN)
        # add rising edge detection on a channel
        GPIO.add_event_detect(PIN_STOP_ALARMA, GPIO.RISING,
                              callback=self.alarmaCallback)

    def alarmaCallback(PIN_STOP_ALARMA):
        "Metodo que desactiva la alarma. INTERRUPT"
        if self._alarm_state == 1:
            pass  # Publique


##########----------    Class   ----------##########
class BrokerManager(threading.Thread):
    """Clase que gestiona el Broker, la activacion y pausa de la alarma
    Ademas de lavisualizacion de los datos obtenidos y sus estados"""

    def __init__(self, main, ip=BROKER_IP, port=1883):
        threading.Thread.__init__(self)
        self.Client = mqtt.Client()
        self._ip = ip
        self._port = port
        self.Client.on_connect = self.on_connect
        self.Client.on_message = self.on_message
        self.archivos = main.archivos

    def set_ip(self, ip):
        "instancia la Ip usada por el Broker"
        self.ip = ip

    def set_port(self, port):
        "intancia el puerto MQTT"
        self.port = port

    def on_connect(self, client, userdata, flags, rc):
        # print("Connected with result code "+str(rc))  # Debug
        client.subscribe("/#")

    # The callback for when a PUBLISH message is received from the server.
    def on_message(self, client, userdata, msg):
        dato = re.sub("b", "", str(msg.payload))
        dato = re.sub("'", "", str(dato))
        try:
            name = self.archivos[msg.topic]
            print(name)
            self.add_dato(name, dato)
        except:
            print("Topico no valido")

    def add_dato(self, archivo, dato):
        """"Guarda un nuevo dato, si el archivo no existe lo creea"""
        # print(dato)
        a = open(archivo, 'a')
        a.write(time.strftime("%H:%M:%S") + "," + (dato) + "\n")
        a.close()

    def connect(self):
        self.Client.username_pw_set(USER, password=PASSWORD)
        self.Client.connect(self._ip, self._port, keepalive=15)

    def disconnect(self):
        self.Client.disconnect()

    def run(self):
        self.Client.loop_forever()


class main():
    def __init__(self):
        self.ruta = "/home/data/"
        self.csv = Archivos()
        self.archivos = {}

        self.BrokerManager = BrokerManager(self, ip=BROKER_IP, port=1883)
        self.BrokerManager.connect()
        self.BrokerManager.start()  # inicia el hilo

        self.hilo_padre = {}
        self.hilo_hijo = {}
        self.list_topic = {}
        self.generate_topic()
        # print(self.archivos)
        # print(self.list_topic)
        # for i in self.archivos:
        #    print("key "+  str(i)+ "  "+"value " + str(self.archivos[i]))
        print("Modo infinito")
        a = 0
        while True:  # a < 500:
            sleep(1)
            a = a + 1
            print("halo")
        self.BrokerManager.disconnect()

    def generate_topic(self):
        c = 0
        f = "/" + CULTIVO["TIPO_CULTIVO"]
        for i in LIST_SENSOR:
            # print("a"+i)
            for m in LIST_SENSOR[i]:
               # print(m)
                if "SENSOR" in m:
                    for n in LIST_SENSOR[i][m]:
                        topic = f + \
                            str(LIST_SENSOR[i][m][n][0]) + "/" + i + "/" + m
                        self.list_topic["topic_" + str(c)] = topic
                        name = str(LIST_SENSOR[i][m][n][1]) + "/" + i + "/" + m
                        name = re.sub("/", "_", name)
                        self.add_file(
                            name, topic, LIST_SENSOR[i][m][n][1], "," + LIST_SENSOR[i]["LOCATION"], i, m)
                        c = c + 1

    def add_file(self, name, topic, var, location, nodo, sensor):
        """Crea un archivo nuevo y lo agrega al diccionario """
        name = self.ruta + str(name) + "_" + \
            time.strftime("%d_%m_%y") + "_" + ".csv"
        self.archivos[topic] = name
        # print(topic)
        self.csv.crear_file(
            name, BROKER["NUMBER_BROKER"], location, nodo, sensor, var)

    def add_hilos(self, hilo_padre, hilo_hijo):
        cola = Queue.Queue()
        self.hilo_padre[hilo_padre] = Recepcion(cola)
        cola = Queue.Queue()
        self.hilo_hijo[hilo_hijo] = cola

    # def hilos(self):
    #    pass


##########----------    Main   ----------##########
if __name__ == '__main__':
    main = main()

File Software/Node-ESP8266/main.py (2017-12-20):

"""
    DESCRIPCI?N...
    This software is free, licensed y distributed under GPL v3.
    (see COPYING) WITHOUT ANY WARRANTY.
    You can see a description of license here: http://www.gnu.org/copyleft/gpl.html
    Copyright(c) 2017 by fandres "Fabian Salamanca" <fabian.salamanca@openmailbox.org>
    Distributed under GPLv3+
    Based On https://github.com/fandres/Monitor-heladas/blob/master/Code/main.py
    Author  - Fabian A. Salamanca F (@fandres).
            - Marlon mauricio Moreno (@mau_rinc2010).
    Hardware: ESP8266
    Pin distribution(Default)
    Pin 4   ->  Pin sensor(DHT11/DHT22), Data(IN)
    Pin 2   ->  Debug Visual(Default=Off), Led On Userled: for development board ESP8266
"""


from MQTT import MQTT
from wifi import WIFI
from cultivo import Cultivo
from debug import debug_mode
import machine


if __name__ == '__main__':
    # configurando RTC.ALARM0
    rtc = machine.RTC()
    rtc.irq(trigger=rtc.ALARM0, wake=machine.DEEPSLEEP)
    # Si el dispositivo desperto de el modo deep sleep
    if machine.reset_cause() == machine.DEEPSLEEP_RESET:
        # print('Desperto del modo deep sleep')  # Debug
        try:
            debug = debug_mode(True)  # True Or False
            wifi = WIFI(debug)
            mqtt = MQTT(debug)
            wifi.connect()
            cultivo = Cultivo(debug, mqtt)
            cultivo.read_sensores()
            cultivo.send_data()
        except:
            import machine
            machine.reset()
    rtc.alarm(rtc.ALARM0, 10000)
    machine.deepsleep()

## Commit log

2017-09-24 Codigo de sonda usando clases
2017-09-25 Addes Class DHT22 (Module: sensores)
2017-09-25 Clase para gestionar el modo debug
2017-09-26 Cambios a la clase DTH22
2017-09-26 PEP-8 and os.debug(UART0)
2017-09-26 Manejo de varios sensores declarados desde config.py
2017-09-26 imports PEP-8 printDebugMode
2017-09-26 Modificación de clase cultivo para enviar datos usado MQTT
2017-09-26 Bug Fixed (Debug On/Off)
    [MQTT.py, cultivo.py, debug.py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]
2017-09-27 Added 3D-Model (sketch): Sonda
    [18650-by_Nursultan_Uzbekov.stp, Allwinner-H2.SLDPRT, Boderboard - Orange Pi zero v1.1.SLDPRT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]
2017-09-27 Created Sketch PCB
    [FrosTool_ESP8266.kicad_pcb, FrosTool_ESP8266.sch]
2017-10-04 Added Schematic: libraries, power and sensors
    [FrosTool_ESP8266.sch]
2017-10-06 Add sistema de carga al esquematico
    [FrosTool_ESP8266.sch]
2017-10-08 Added sheet Linear Li-lon Battery Charger
    [FrosTool_ESP8266.sch, TP4056.sch]
2017-10-08 Design proposal Node_1
    [Node_1.stl, support_bat.step, support_bat.stl]
2017-10-09 ESP8266 Mod Prog
    [FrosTool_ESP8266.sch, TP4056.sch]
2017-10-09 Added Pin Diagram (ESP8266)
2017-10-09 IO CONN
    [FrosTool_ESP8266.sch]
2017-10-11 Removed the old TP4056 component
    [FrosTool_ESP8266.sch, TP4056.sch]
2017-10-11 Added NETList
    [FrosTool_ESP8266.sch, TP4056.sch]
2017-10-12 Rules Design Drill Pads
2017-10-13 components located
    [FrosTool_ESP8266-B.Cu.gbr, FrosTool_ESP8266-B.Mask.gbr, FrosTool_ESP8266-B.SilkS.gbr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]
2017-10-14 Tracks and Vias improvement Bug Fixed: Pads Regulator
    [FrosTool_ESP8266.kicad_pcb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]
2017-10-14 Added Schematic
2017-10-14 Added zones (F.cu, B.cu -> GND)
    [FrosTool_ESP8266.kicad_pcb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]
2017-10-17 F.Fab, B.Fab
    [FrosTool_ESP8266.kicad_pcb, FrosTool_ESP8266.sch]
2017-10-17 Added Pin Extra: BAT+
    [FrosTool_ESP8266.csv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]
2017-10-22 Model PCB FrosToolESP8266
    [FrosTool_ESP8266.FCStd, Node2.fcstd]
2017-10-23 Model Case: Revolution
    [Case_FrossTool.fcstd]
2017-10-24 Bug Fixed: Mode Debug -> unsupported type error
    [MQTT.py]
2017-10-24 Added proposed Node
    [Case_FrossTool.fcstd]
2017-10-28 Added proposal 2 node
    [Case_FrossTool.fcstd, case_Node.fcstd]
2017-10-30 Visual Debug Added parameter to the printDebug method
2017-11-01 device to sleep (deep sleep)
2017-11-21 Added STATUS LED
2017-12-13 Plantilla para almacenado de los datos
2017-12-18 Generacion de archivos csv
2017-12-20 Archivo de configuación del broker
    [config.py]
2017-12-20 Software broker 1.4, gestion de informes y control de accesos de topicos no autorizado
    [config.py, main.py]
2018-01-22 - Implemented authentication by user and password. For the client used to manage the Broker (Orange PI) - Change from "localhost" to manual ip configuration: "localhost" -> "192.168.42"
    [config.py, main.py]
2018-01-29 Model Support. Added STL parts
    [SUPP_2.step, SUPP_2.stl, SUPP_3.stl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]
2018-03-08 Aggregates 3D Models: Esp8266 (by Christophe Chaloin) and model adapted by fandres of ILI9341-2_8 (by Christophe Chaloin)
    [ESP8266-12.FCStd, ILI9341-2_4.FCStd, ILI9341-2_4.step]
2018-03-08 3D Models Added and relocated, part 1.
    [Case_Broker.fcstd]
2018-03-08 Added Stencil
    [F.Mask.stl]
2018-03-10 Ignore Design temp
    [Case_Broker.fcstd, Node2.fcstd, SUPP_2.step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]
2018-03-20 Added Model: Case Broker
    [Case_Broker-A.stl, Case_Broker-B.stl, ILI9341-2_4.FCStd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]
2018-03-30 Widget para pantalla 2.4 pulgadas
2018-04-01 Drill 0,8 mm FrosTool And Eco-Tec
    [Case_Broker-A.stl]
2018-05-29 Bug Fixed (R10k x2), No Programing, Debug_led(USERLED)
    [FrosTool_ESP8266.sch, TP4056.sch]
